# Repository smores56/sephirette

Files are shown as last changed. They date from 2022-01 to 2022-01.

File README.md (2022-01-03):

The Sephirette
==============

The Sephirette is a split 34-key keyboard with pinky clusters. It is the split
version of the [Osprette MX][osprette-mx], designed by me, which itself was inspired by
the [Balbuzard][balbuzard] by brow.

[osprette-mx]: https://github.com/smores56/osprette-mx
[balbuzard]: https://github.com/brow/balbuzard

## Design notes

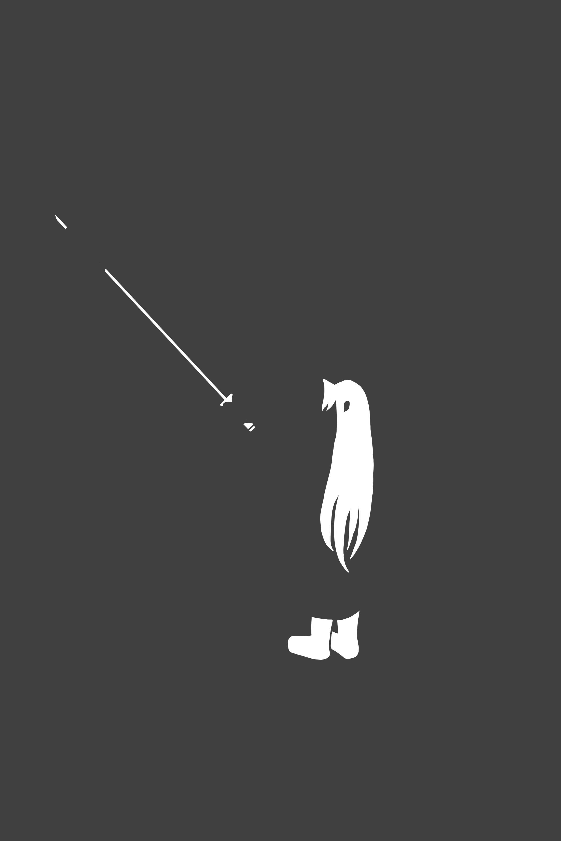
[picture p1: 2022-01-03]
art/sephirette-paste.png

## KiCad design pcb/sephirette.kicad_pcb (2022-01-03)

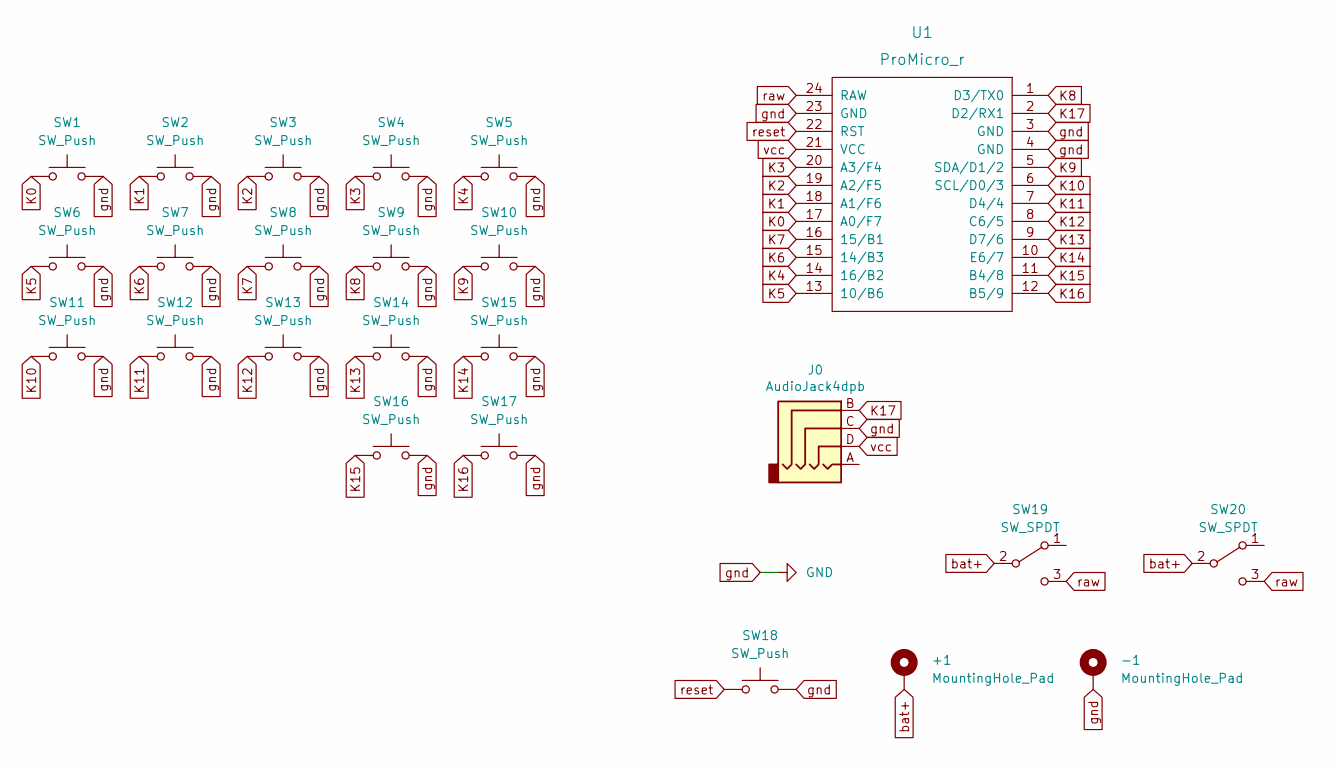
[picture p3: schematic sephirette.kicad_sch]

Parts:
+1: MountingHole_Pad; 1pin_conn
-1: MountingHole_Pad; 1pin_conn
J0: AudioJack4dpb; MJ-4PP-9
SW1, SW2, SW3, SW4, SW5, SW6, SW7, SW8, SW9, SW10, SW11, SW12, SW13, SW14, SW15, SW16, SW17: SW_Push; Kailh_socket_MX_optional_reversible
SW18: SW_Push; ResetSW
SW19, SW20: SW_SPDT; SW_SPDT_PCM12
U1: ProMicro_r; ProMicro_v3.5

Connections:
K0: SW1.1, U1.17 (A0/F7)
K1: SW2.1, U1.18 (A1/F6)
K2: SW3.1, U1.19 (A2/F5)
K3: SW4.1, U1.20 (A3/F4)
K4: SW5.1, U1.14 (16/B2)
K5: SW6.1, U1.13 (10/B6)
K6: SW7.1, U1.15 (14/B3)
K7: SW8.1, U1.16 (15/B1)
K8: SW9.1, U1.1 (D3/TX0)
K9: SW10.1, U1.5 (SDA/D1/2)
K10: SW11.1, U1.6 (SCL/D0/3)
K11: SW12.1, U1.7 (D4/4)
K12: SW13.1, U1.8 (C6/5)
K13: SW14.1, U1.9 (D7/6)
K14: SW15.1, U1.10 (E6/7)
K15: SW16.1, U1.11 (B4/8)
K16: SW17.1, U1.12 (B5/9)
K17: J0.B, U1.2 (D2/RX1)
bat+: +1.1, SW19.2 (B), SW20.2 (B); also elsewhere on the board
gnd: -1.1, J0.C, SW1.2, SW2.2, SW3.2, SW4.2, SW5.2, SW6.2, SW7.2, SW8.2, SW9.2, SW10.2, SW11.2, SW12.2, SW13.2, SW14.2, SW15.2, SW16.2, SW17.2, SW18.2, U1.3 (GND), U1.4 (GND), U1.23 (GND); also elsewhere on the board
raw: SW19.3 (C), SW20.3 (C), U1.24 (RAW)
reset: SW18.1, U1.22 (RST)
vcc: J0.D, U1.21 (VCC)

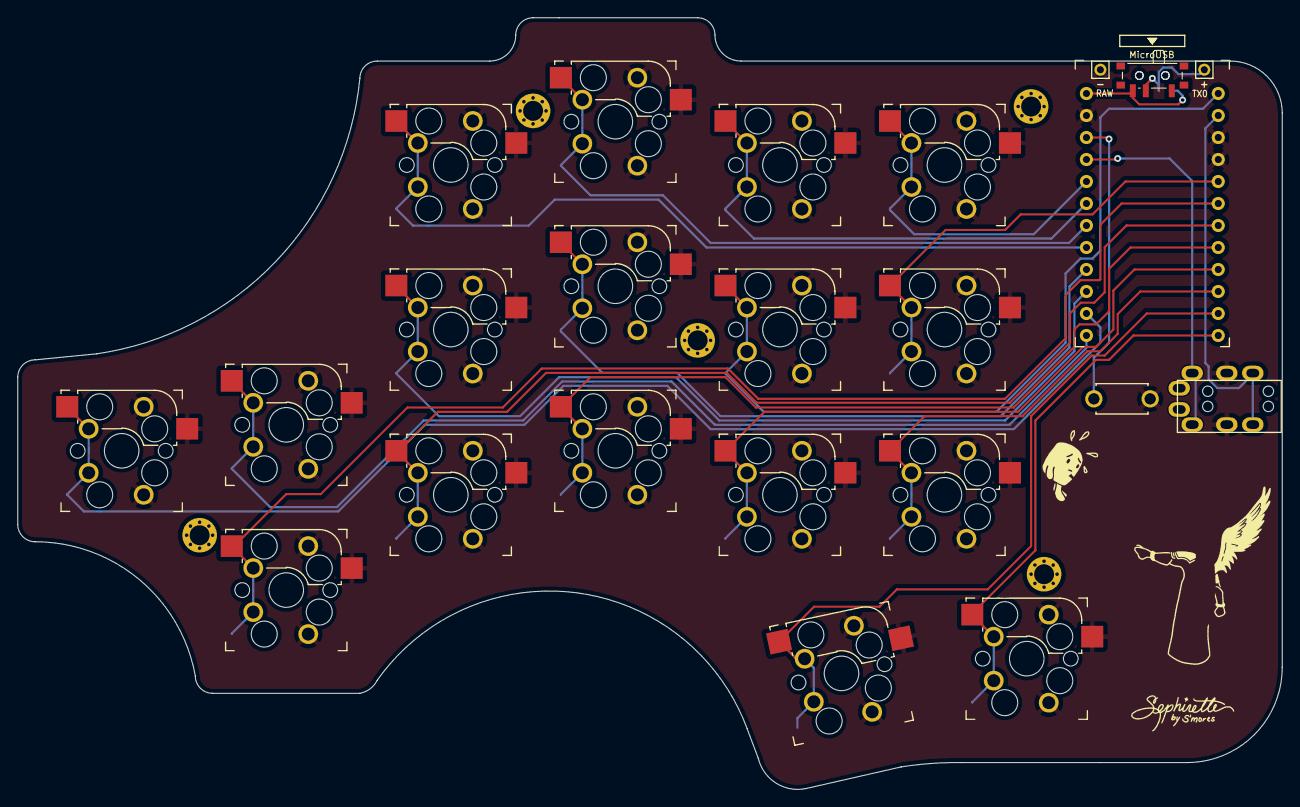
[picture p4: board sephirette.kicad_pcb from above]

Board: 2 copper layers, 146.0 x 89.1 mm, 29 parts (1 on the bottom side), 23 nets.

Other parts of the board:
+: MountingHole_Pad; 1pin_conn
-: MountingHole_Pad; 1pin_conn
Ref**: Val**; M2_HOLE_v3
Ref**#2, Ref**#3, Ref**#4, Ref**#5: Val**; M2_HOLE_v3

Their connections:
bat+: +.1; also elsewhere on the board
gnd: -.1; also elsewhere on the board

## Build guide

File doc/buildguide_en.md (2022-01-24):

# Build Guide

This is the build guide for [the Sephirette](https://www.smoresboards.com/product/sephirette).

## Parts

### Required

| Name | Count | Remarks |
|:-|:-|:-|
| PCB's | 2 | |
| Pro Micros | 2 | |
| 12-Pin Sockets | 4 | |
| Reset Switches | 2 | |
| Key Switches | 34 | |
| Keycaps | 34 | |

#### Wired Build

| Name | Count | Remarks |
|:-|:-|:-|
| TRRS Jacks | 2 | |
| TRRS (4 poles) Cable | 1 | |
| Micro USB/USB-C Cable | 1 | According to the selected Pro Micro-compatible MCU |

#### Wireless Build

| Name | Count | Remarks |
|:-|:-|:-|
| Power Switches | 2 | |
| Batteries | 2 | |

### Optional

| Name | Count | Remarks |
|:-|:-|:-|
| Hot-Swap Sockets | 34 | |
| Top Plates | 2 | |
| Bottom Plates | 2 | |
| M2 Standoffs (3mm) | 20 | |
| M2 Bolts (8mm) | 10 | |
| M2 Bolts (3mm) | 10 | |
| M2 Washers | 10 | |
| Bumpons | 8-10 | |

## Assembly

If you are going to use hot-swap sockets, solder them on the **bottom** side of each half first.
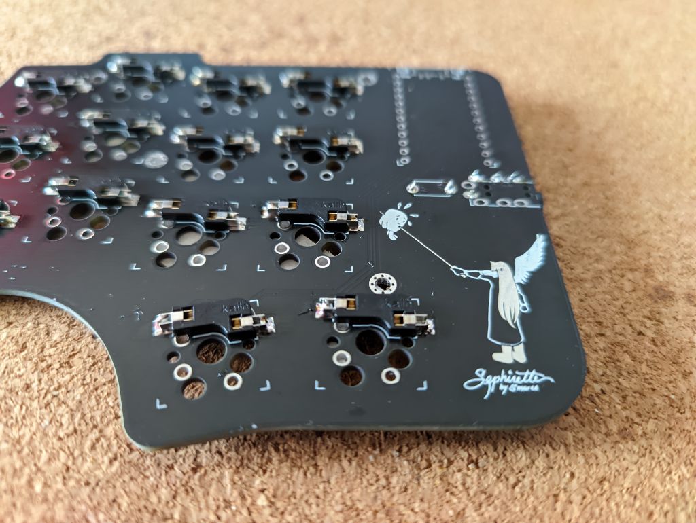
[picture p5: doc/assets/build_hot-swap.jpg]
solder_hot-swap-sockets


Solder the reset switches and TRRS jacks on the **top** of the PCB's.
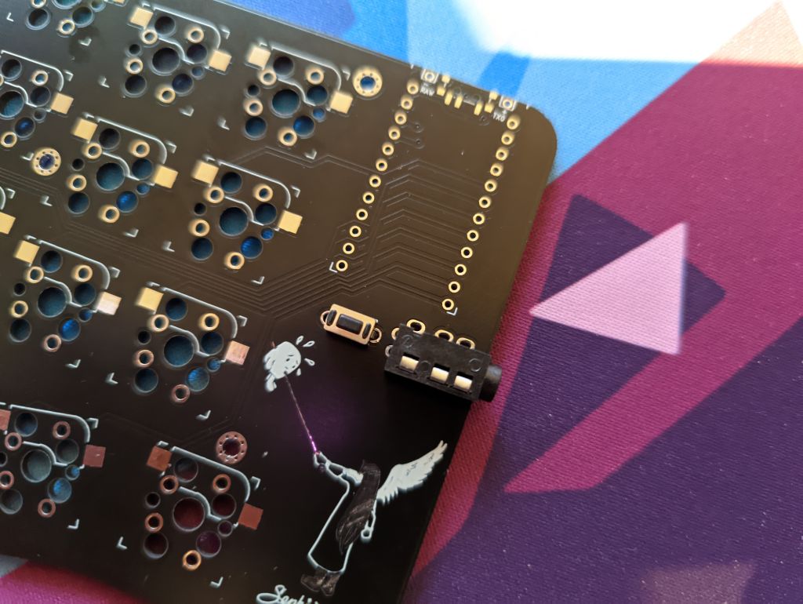
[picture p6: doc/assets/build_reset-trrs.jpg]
solder_reset-switch_and_trrs-jack


Solder the Pro Micros using the 12-pin sockets on the **top** side of the PCB's.
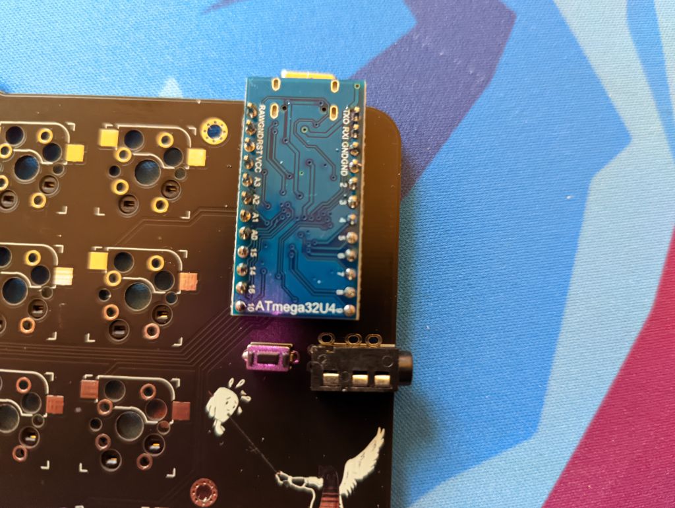
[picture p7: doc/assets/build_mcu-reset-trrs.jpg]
solder_mcu


**NOTE:** Make sure to properly align your Pro Micro MCU pins with the text on the PCB's. The left half has the Pro Micro face-down and the right half has it face-up.
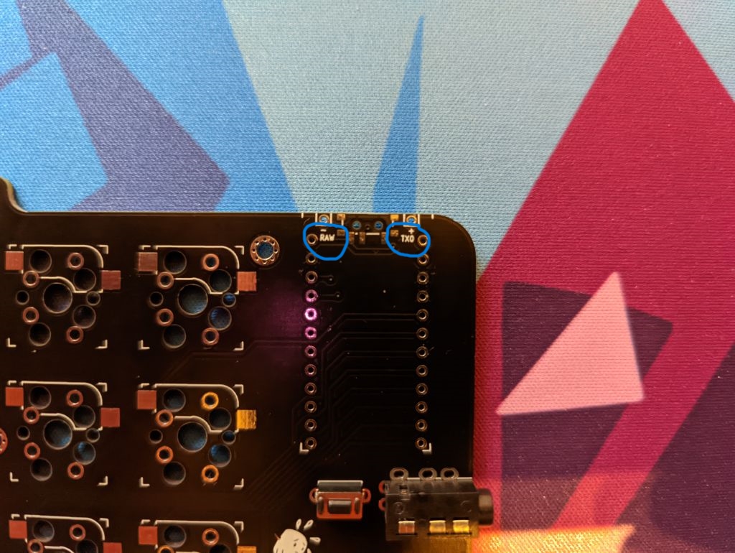
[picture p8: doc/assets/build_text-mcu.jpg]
position_mcu

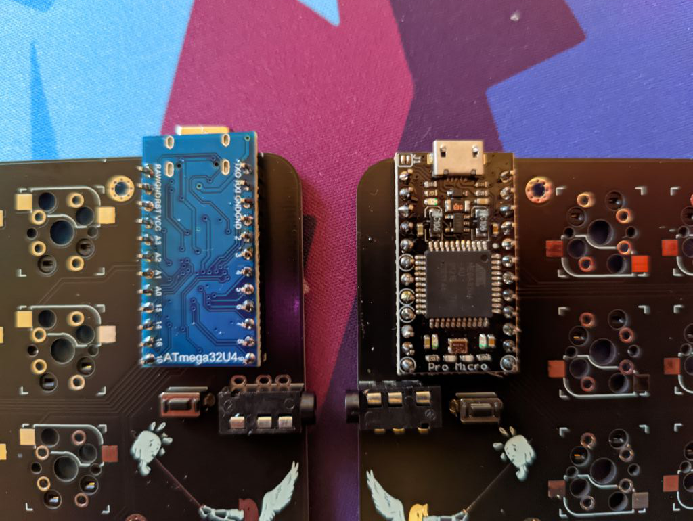
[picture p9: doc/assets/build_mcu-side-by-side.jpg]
mcus_side_by_side


If you are going to use switch plates, now you should screw the 8mm screws into the switch plates from the **top**, held in place by 5 of the 3mm standoffs per half under the switch plates. 
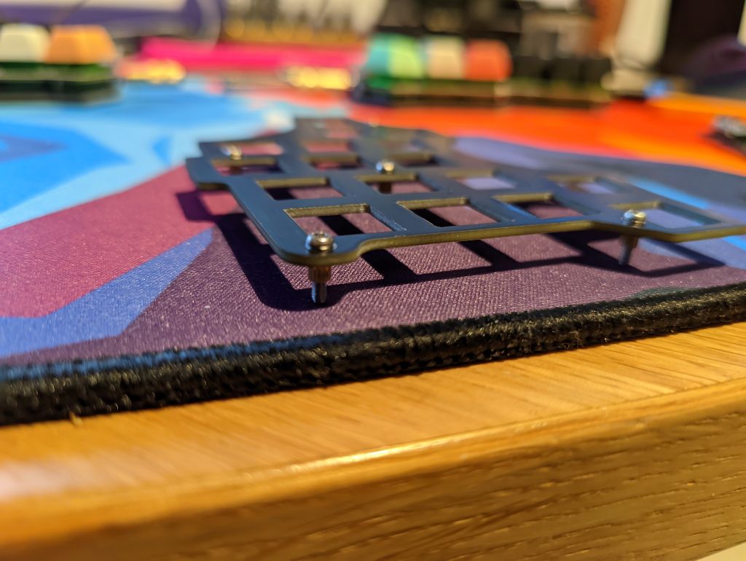
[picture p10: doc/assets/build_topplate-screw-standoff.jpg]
screw_topplate_standoff


Insert 4 switches in the corners and don't forget to properly align them with the hot-swap sockets (if you are using them).
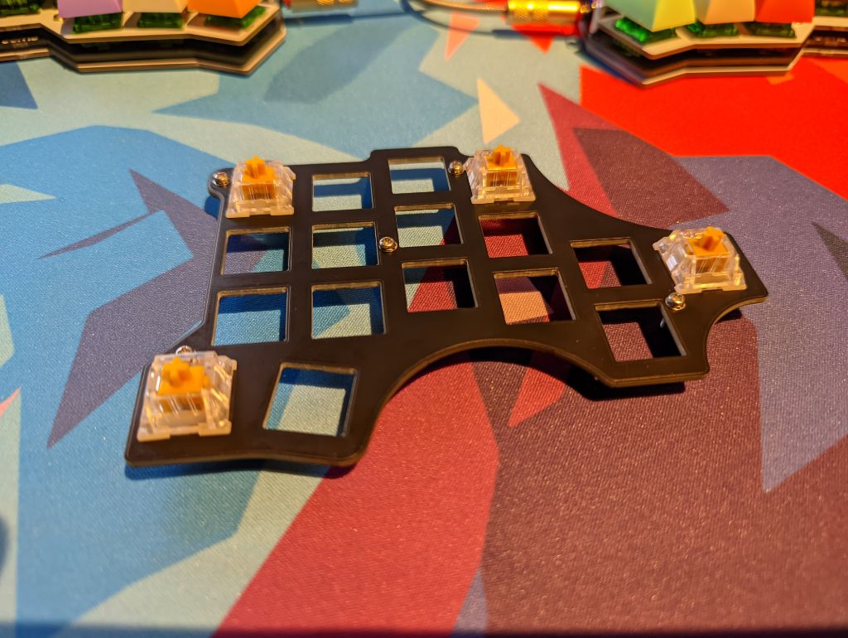
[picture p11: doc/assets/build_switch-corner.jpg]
switches_in_corner


Place the washers onto the PCB's over top the mounting holes.
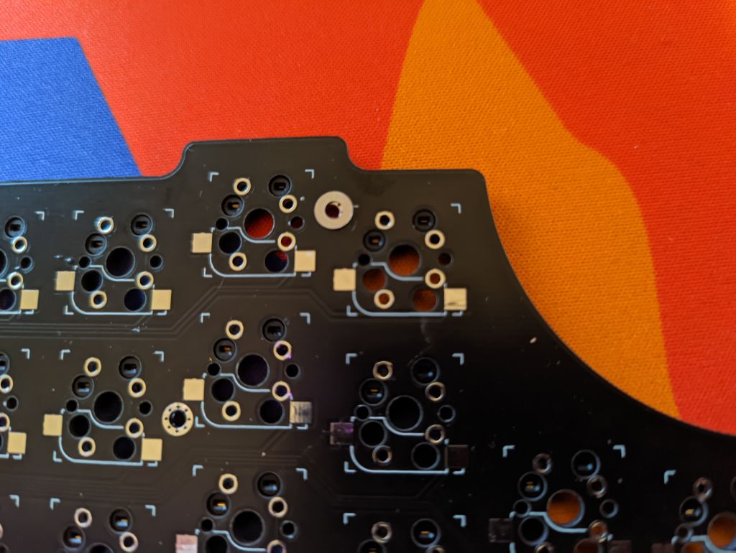
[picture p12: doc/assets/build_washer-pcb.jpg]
washers_on_pcb


Align the 8mm screws (poking out of the bottoms of the switch plates) with the washers on the PCB's and gently press the 4 switches into place. After that, you can add the remaining switches.
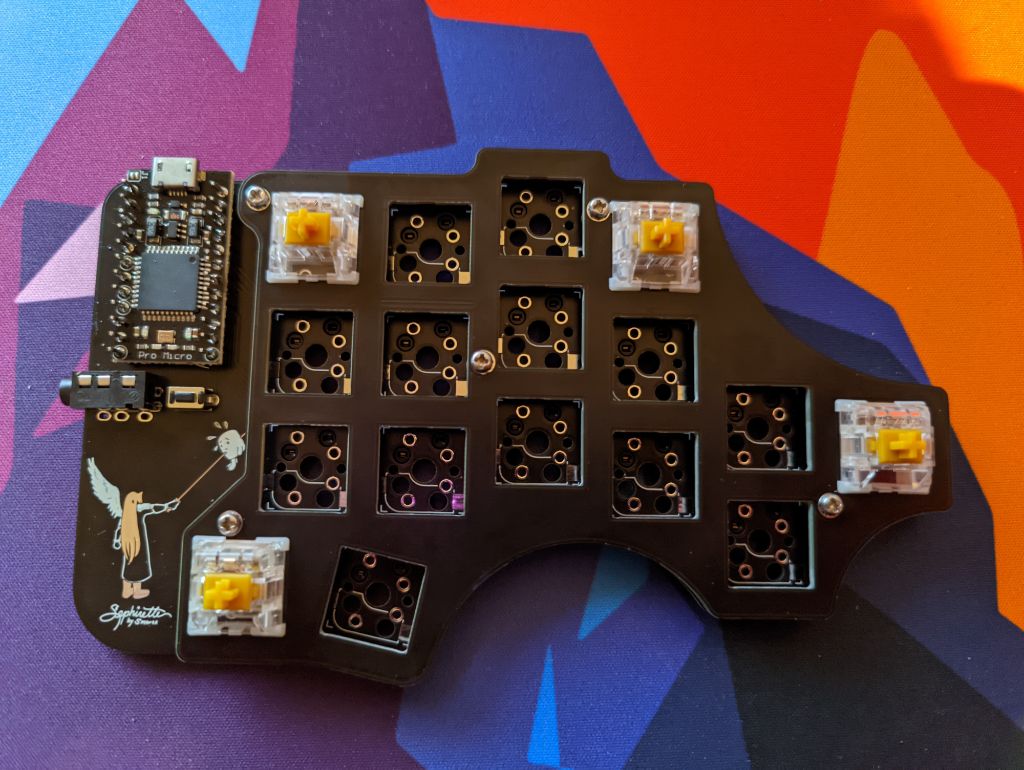
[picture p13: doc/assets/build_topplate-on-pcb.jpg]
topplate_on_pcb


On the backsides of the PCB's, screw in the remaining 3mm standoffs.
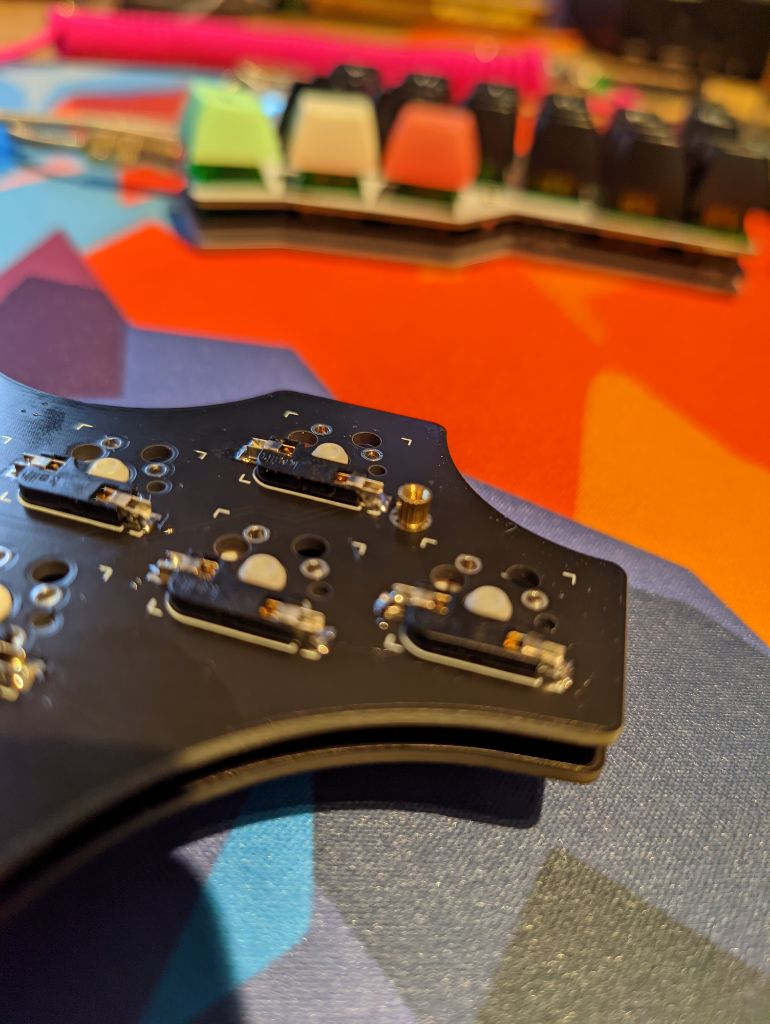
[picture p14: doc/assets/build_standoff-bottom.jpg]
standoffs_on_the_back


With the boards upside-down, put the bottom plates on the standoffs and screw in the 3mm screws. Then add the bumpons.
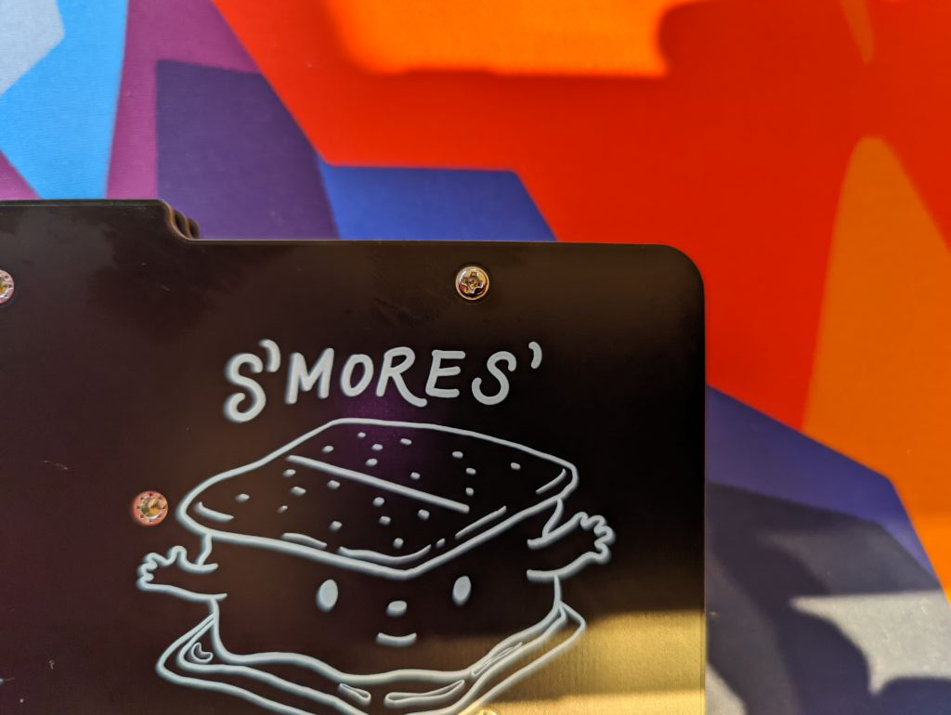
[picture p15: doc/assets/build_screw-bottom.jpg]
screw_bottom


Add some keycaps and you're good to go!
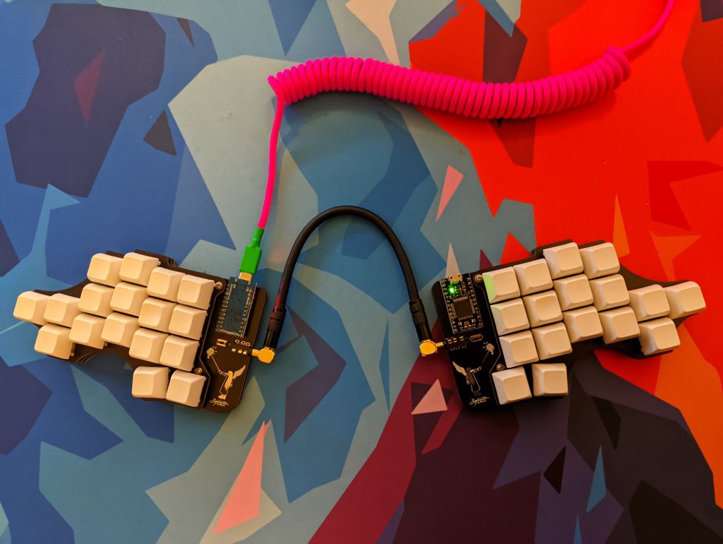
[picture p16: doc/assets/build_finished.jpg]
build_finished


## Firmware

You can use the [QMK config](https://github.com/smores56/qmk_firmware/tree/master/keyboards/clog) of the clog or ZMK config in the main repo of [ZMK](https://zmk.dev/). (This board uses the Clog firmware and will be named as such on your computer.)

If you want to use the default keymap, you can just grab [this firmware](assets/clog_default.hex) and flash it right away.
